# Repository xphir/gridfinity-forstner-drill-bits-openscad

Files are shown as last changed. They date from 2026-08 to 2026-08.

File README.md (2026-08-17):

# gridfinity-forstner-drill-bits-openscad

Parametric Gridfinity bin for Forstner drill bits. Bits lie flat in an open
tray, cradled by two notched rails, alternating head-to-tail ("top and
tail") so each bit's head sits next to a neighbour's narrow shaft — packing
the set far tighter than standing them upright would.

Built on [kennetek/gridfinity-rebuilt-openscad](https://github.com/kennetek/gridfinity-rebuilt-openscad)
for the base profile, stacking lip, walls, and magnet/screw holes. This repo
only adds the rail geometry that cradles the bits.

Inspired by [PabloFernandez](https://www.printables.com/@PabloFernandez)'s
[Gridfinity Bins for Forstner Drill Bits](https://www.printables.com/model/870351-gridfinity-bins-for-forstner-drill-bits)
on Printables.

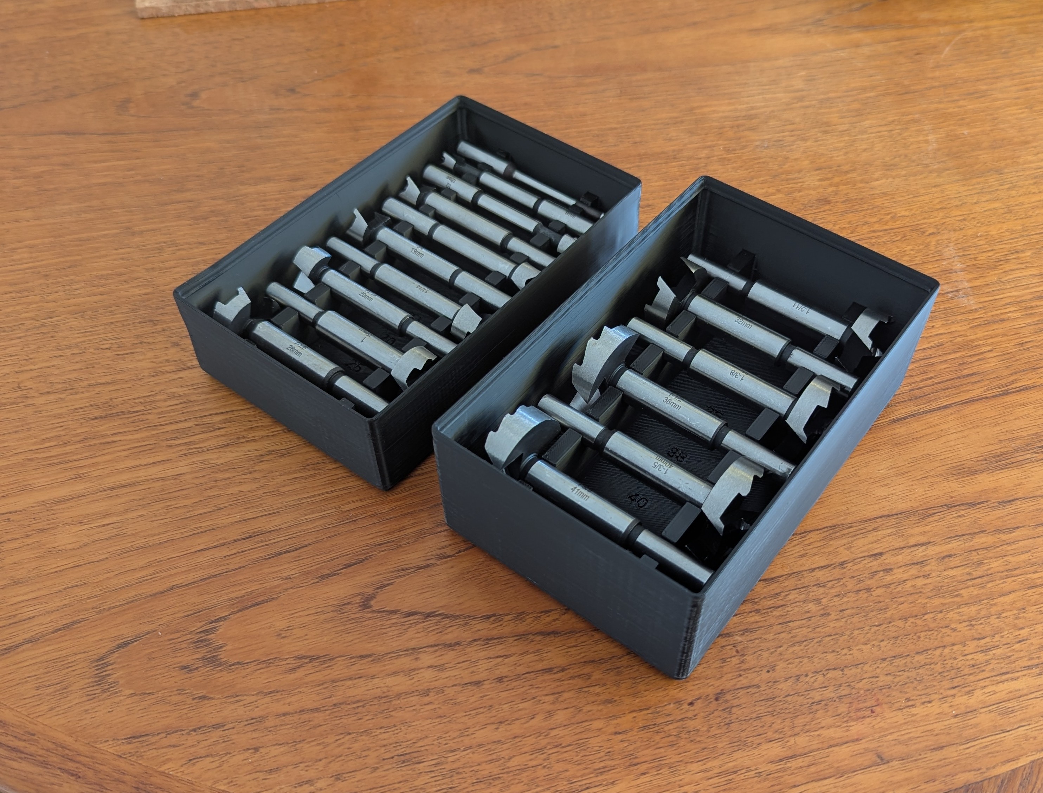
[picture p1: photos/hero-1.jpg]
Two printed trays, one sized for a small-bit set and one for a large-bit set


## Setup

The library is a git submodule, so clone with `--recurse-submodules`:

```bash
git clone --recurse-submodules https://github.com/xphir/gridfinity-forstner-drill-bits-openscad.git
```

If you already cloned without that flag:

```bash
git submodule update --init
```

Open `gridfinity_forstner_flat_lib.scad` in [OpenSCAD](https://openscad.org/).

## Usage

The bit list is up to 20 slots (`bit_01_*` through `bit_20_*`), each with its
own `enabled` checkbox — flip a slot on and fill in its dimensions to add a
bit, or leave it off to skip it. Out of the box, only 5 slots are enabled
with generic round sizes (10/15/20/25/30 mm) as a working example — replace
them with your own measurements, or load a known set via **Preset**. All
dimensions are in mm, measured from the head end downwards, five sections
per bit:

- `head_diameter` / `head_length` — the cutting head, the widest part
- `neck_diameter` / `neck_length` — short narrow transition right below the head
- `body_diameter` / `body_length` — the main shaft (most of the bit's length)
- `waist_diameter` / `waist_length` — narrow retention groove just above the shank
- `base_diameter` / `base_length` — the shank that goes in the chuck

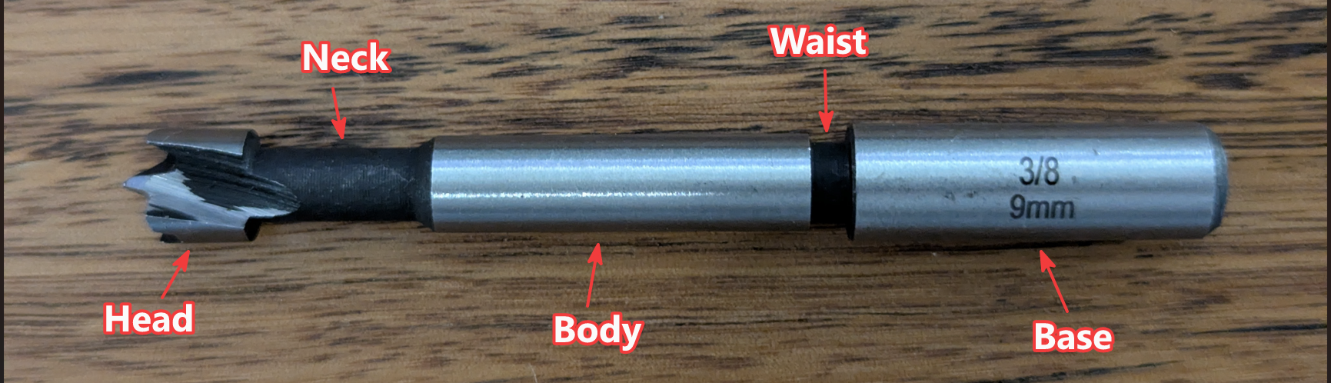
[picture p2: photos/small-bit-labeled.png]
Small Forstner bit segments labelled: head, neck, body, waist, base

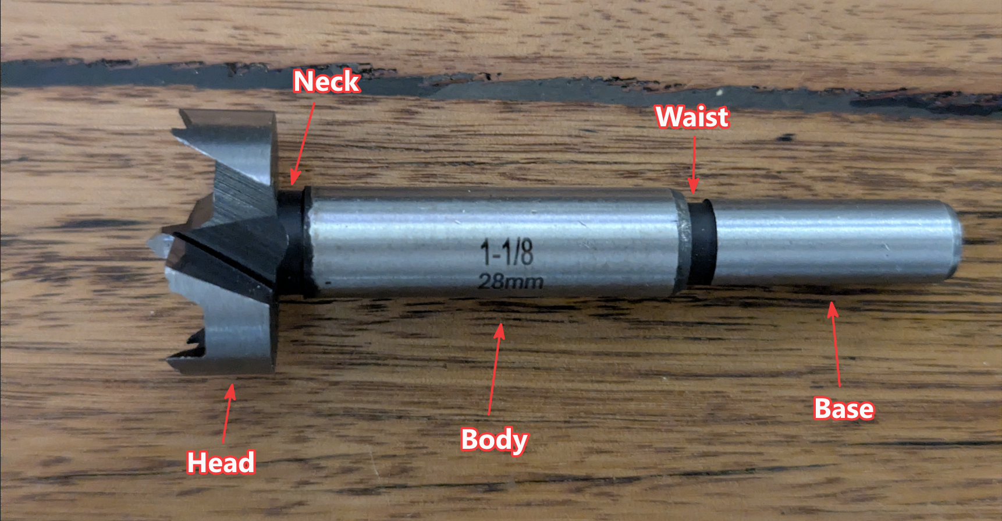
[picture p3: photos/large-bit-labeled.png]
Large Forstner bit segments labelled: head, body, waist, base


Only `head_diameter` needs a value on every enabled bit. Everything else
defaults to `0`, which means "use the matching `default_head_length` /
`default_body_diameter` / etc. value" in the **Bit defaults** section —
handy since most forstner sets share the same head length and shank across
many sizes. Give a bit a non-zero value in any of those fields to override
the default just for that one bit (e.g. if its shaft is a single constant
diameter, set that bit's `base_diameter` equal to its `body_diameter`).

Each bit also has a `mountN` field (`false` = body, `true` = neck), which
picks which of those two diameters actually grips that bit's rails. Most
bits should stay on `body`; switch a bit to `neck` if its body is short or
oddly proportioned next to its neighbours (a small bit whose neck is
proportionally long next to its shank, for example) — the model will warn
in the console if neither rail actually lands on the chosen section.

This scalar-per-field format (rather than a table or list) is deliberately
the most restrictive customizer-compatible shape there is, so it has the
best chance of showing up as editable fields both in the OpenSCAD Customizer
and in MakerWorld's parameter panel — neither reliably renders list-type
parameters.

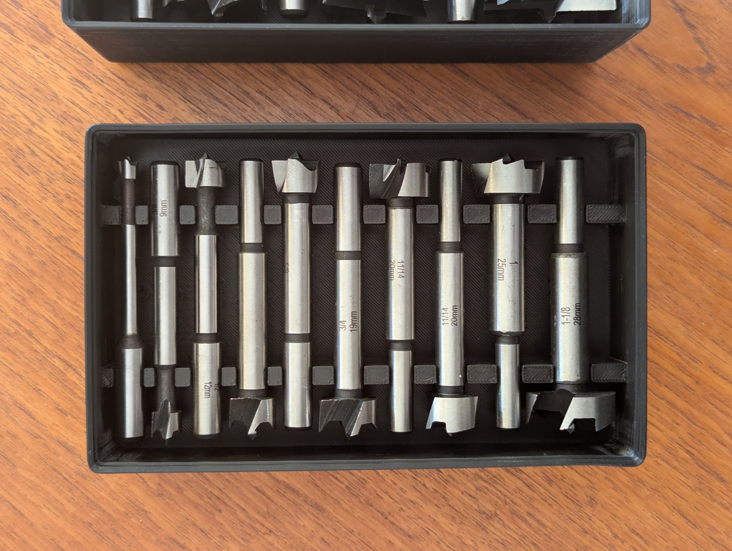
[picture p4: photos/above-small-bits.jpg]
Top-down view of a tray showing bits alternating head-to-tail


Everything else — bin footprint, height, rail spacing, magnet/screw holes,
labels — auto-sizes from the enabled bits, or can be overridden in the
Customizer. See the comments in `gridfinity_forstner_flat_lib.scad` itself
for the full parameter reference.

### Known bit sets

The **Preset** dropdown can load a known set's measurements into the bit
fields for you (currently just the VEVOR 16-piece set). A preset only fills
in *sizes* — one preset row per slot — it never touches the `enabled`
checkboxes, so you can still turn individual slots on/off same as with a
hand-entered list. Pick `None` to go back to editing the fields yourself.

### Splitting a large set across multiple prints

A full 16+ bit set makes for a long tray and a long print. Since rail
spacing is shared across every enabled bit, splitting the set into two
prints — rather than just picking a smaller `grid_x`/`grid_y` — keeps each
print's rail spacing tuned to a narrower size range instead of being
stretched to fit both your smallest and largest bits at once. It also
just plain fits more printer beds — a single tray sized for a full 16+
bit set can easily be longer than many printers' build volume. With the
VEVOR set, for example: enable bits 1–10 for one print, then 11–16 for a
second, by flipping the rest off in **Enabled bits** (works the same way
whether you're using the preset or a hand-entered list).

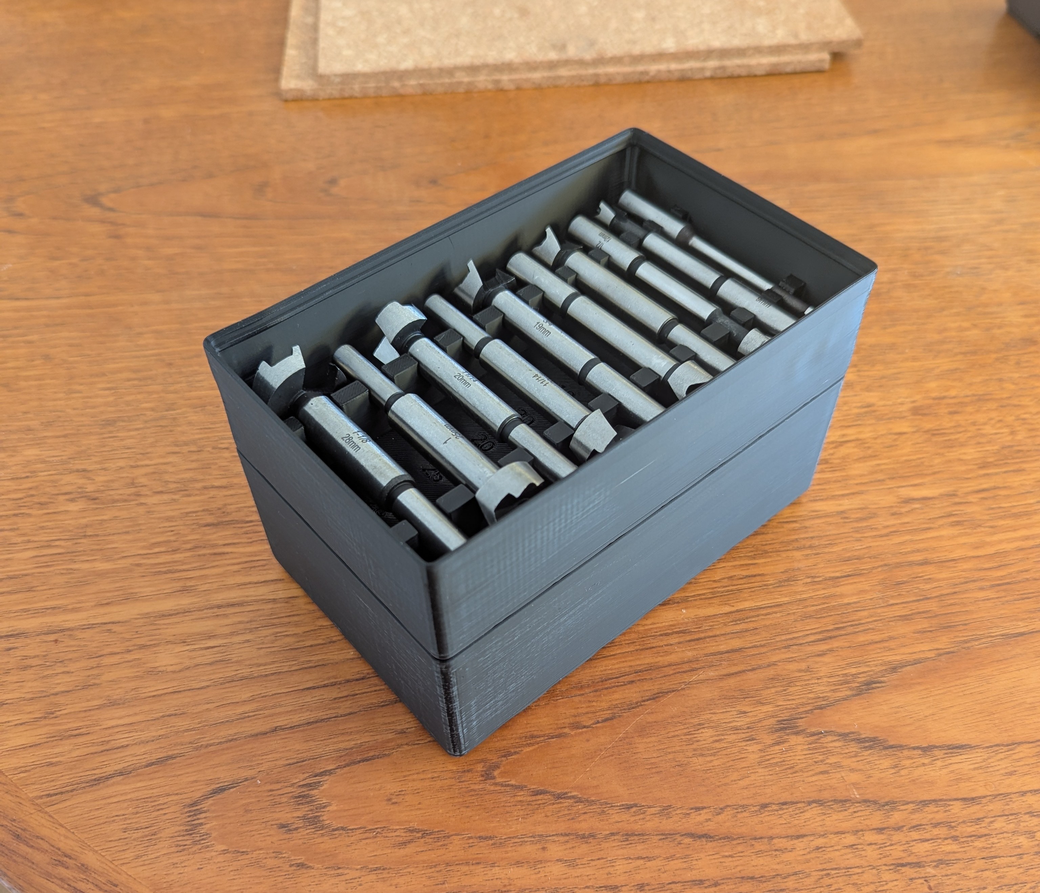
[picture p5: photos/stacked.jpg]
Two trays stacked, one for the small-bit split and one for the large-bit split


### Half-grid footprint

Set `allow_half_units` (in **Bin**) to size the tray in 21 mm half-units
instead of full 42 mm Gridfinity units, for a tighter footprint when a
full unit per row would waste space. It still snaps onto a standard
Gridfinity baseplate.

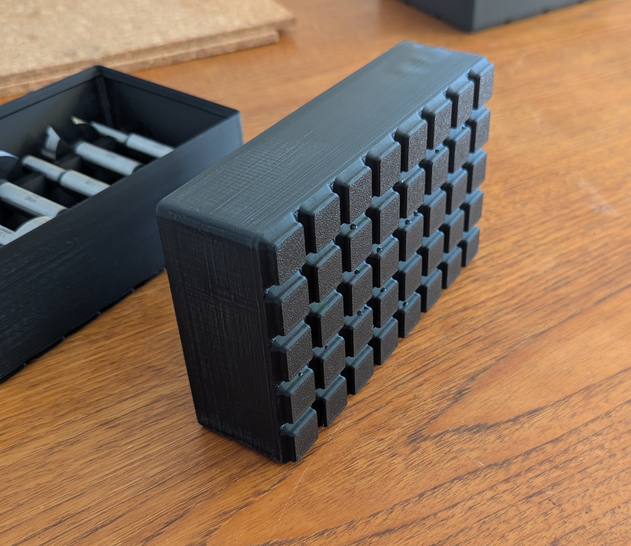
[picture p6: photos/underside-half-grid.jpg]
Underside of a tray printed with the half-grid footprint


### Testing grip/fit before committing to a full print

Set `test_bit` (in **Testing**) to a slot number to render a small, fast
coupon instead of the whole bin — just enough rail to test-fit that one
bit and feel whether the retention pinch actually grips. Much quicker than
re-printing the full tray while dialing in `slot_clearance` and
`grip_pinch` for your printer/filament. Worth doing even with the default
`slot_clearance` — the right value depends on your printer and filament,
and is cheap to check with the coupon before committing to a full tray.

Set `test_all_bits` instead to render one connected, height-reduced rail
strip covering every enabled bit at its real spacing — a single quick
print that checks the whole set's fit, including bit-to-bit spacing, not
just each bit in isolation. It overrides `test_bit` while on.

## Gallery

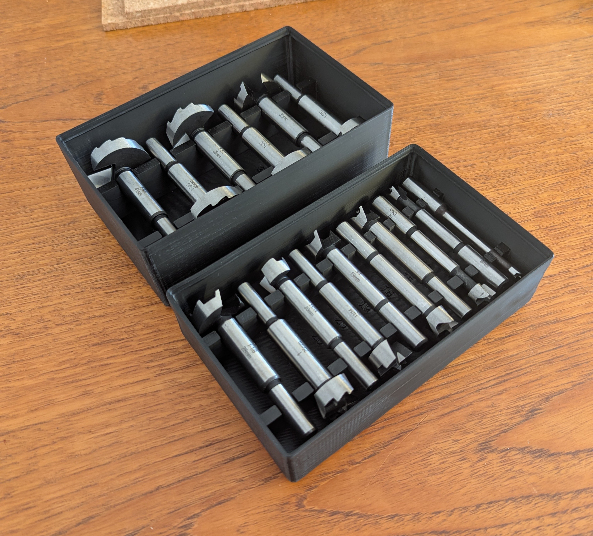
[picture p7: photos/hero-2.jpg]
Angled close-up of both trays

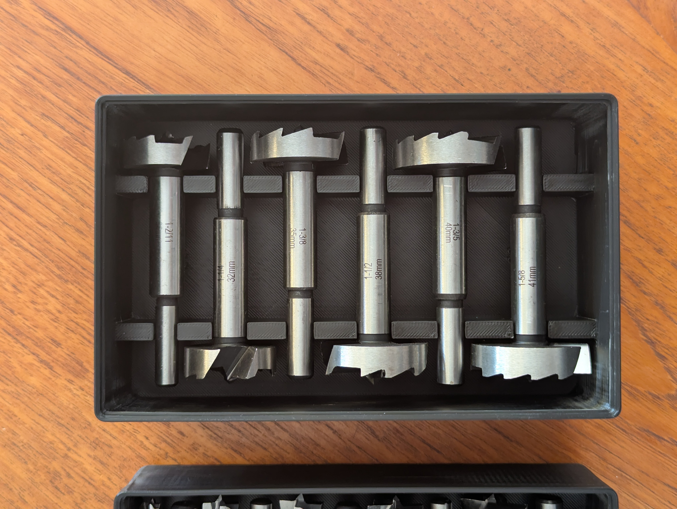
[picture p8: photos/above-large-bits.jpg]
Top-down view of the large-bit tray

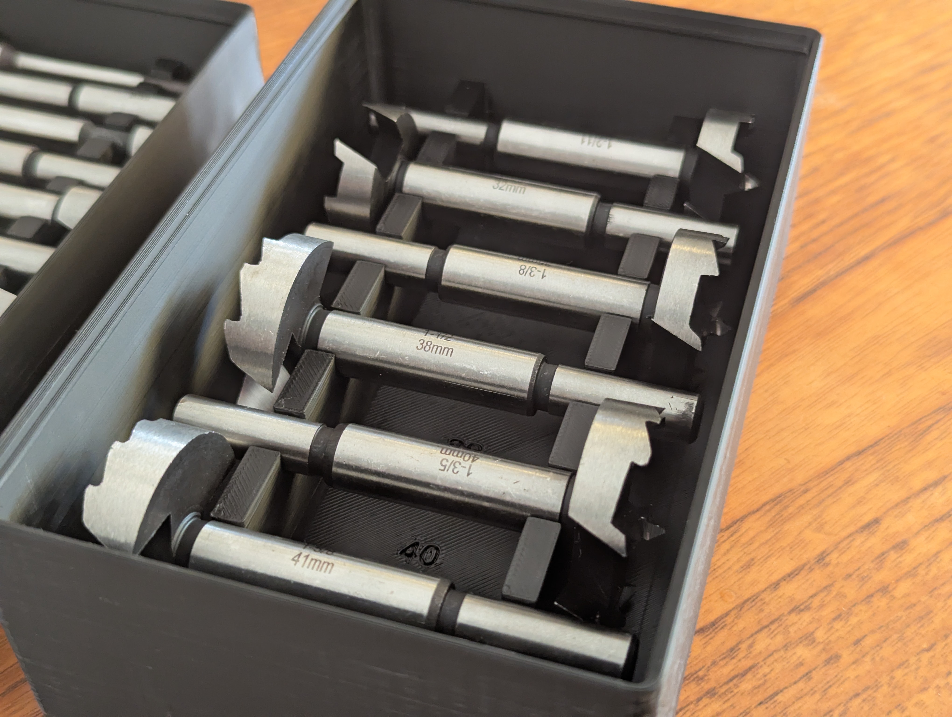
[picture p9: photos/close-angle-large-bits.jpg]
Closer angled view of the large-bit tray


## Status

Verified to compile to a clean manifold solid. First real test print
confirmed the flat-lay/top-and-tail layout works and the retention pinch
gives a real click. At the default `slot_clearance` (0.05 mm) bits click
in and hold well — even fully upside down, nothing falls out — but it can
be a little tight to pull bits back out; try 0.1 mm if you'd rather have
easier removal at the cost of a slightly less snug hold. Use `test_bit` to
check either value on your own printer before committing to a full tray.

Printed in [Siddament Black PLA+](https://siddament.com.au/products/black-pla-1)
on a 0.4 mm nozzle, 0.2 mm layers, Arachne walls, 3 wall loops, 15% gyroid
infill. Some stringing showed up in corners, most likely from damp
filament rather than the model or slicer settings. A ready-to-slice
[`profiles/vevor-16-bit-set.3mf`](profiles/vevor-16-bit-set.3mf) is
included for the VEVOR 16-piece set as a starting point.

The VEVOR preset's dimensions come from a real set; anything you enter by
hand should still be measured against your own bits before printing.

## License

MIT — see [LICENSE](LICENSE). The bundled `gridfinity-rebuilt-openscad`
submodule is separately licensed (also MIT) by its own authors.

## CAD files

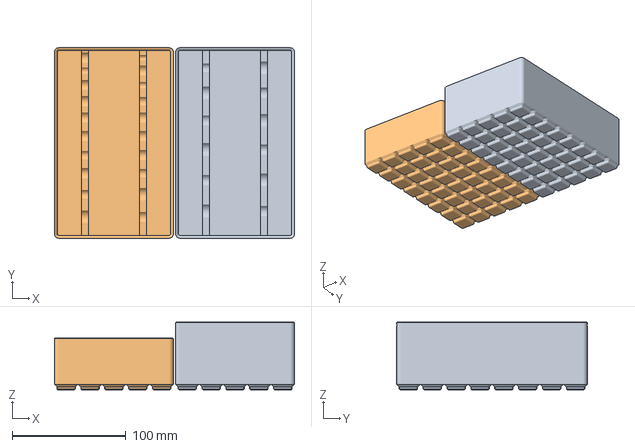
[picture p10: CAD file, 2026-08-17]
profiles/vevor-16-bit-set.3mf
211.0 x 167.5 x 59.5 mm
ParametricModelMaker(4).stl
ParametricModelMaker(3).stl

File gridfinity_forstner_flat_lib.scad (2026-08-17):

// =============================================================================
//  GRIDFINITY FORSTNER BIT HOLDER  -  flat lay, top-and-tail
//  Built on kennetek's gridfinity-rebuilt-openscad library.
// -----------------------------------------------------------------------------
//  SETUP
//    git clone https://github.com/kennetek/gridfinity-rebuilt-openscad.git
//  and put the resulting folder next to this file:
//
//    my-project/
//      gridfinity_forstner_flat_lib.scad     <- this file
//      gridfinity-rebuilt-openscad/          <- the cloned library
//
//  The library owns the base profile, stacking lip, walls and magnet/screw
//  holes. This file only adds the two notched rails that cradle the bits.
//
//  F5 = preview, F6 = render, then File > Export > Export as STL.
// =============================================================================

include <gridfinity-rebuilt-openscad/src/core/standard.scad>
use <gridfinity-rebuilt-openscad/src/core/bin.scad>
use <gridfinity-rebuilt-openscad/src/core/gridfinity-rebuilt-holes.scad>
use <gridfinity-rebuilt-openscad/src/core/gridfinity-rebuilt-utility.scad>


// =============================================================================
//  BIT LIST -- up to 20 slots (Bit defaults, then Enabled bits, then Bit
//  list, near the bottom of the Customizer). Turn a slot off in "Enabled
//  bits" to skip it entirely; disabled slots don't affect sizing/layout at
//  all. All dimensions in mm,
//  measured from the head end downwards, five sections per bit (see
//  photos/ for a labelled reference):
//
//    head  -- the cutting head, the widest part
//    neck  -- short narrow transition right below the head
//    body  -- the main shaft (most of the bit's length)
//    waist -- narrow retention groove just above the shank
//    base  -- the shank that goes in the chuck
//
//  head_diameter is always read from the bit's own field -- it's the one number
//  that actually distinguishes one bit from another. Every other field
//  (head_length, neck_diameter, neck_length, body_diameter, body_length, waist_diameter, waist_length,
//  base_diameter, base_length) defaults to 0, meaning "use the matching default_*
//  value in Bit defaults" -- most forstner sets share the same head length
//  and shank across many sizes, so this saves re-typing the same numbers
//  20 times. Give a bit its own non-zero value in any of those fields to
//  override the default just for that bit.
//
//  mountN picks whether that bit's rails grip its neck or its body
//  (default body). Rather than exactly track where the neck/body/waist
//  boundaries physically fall -- fragile once bit proportions vary this
//  much between sizes -- the seat at BOTH rails for a bit is simply sized
//  to whichever one is chosen, treated as if it ran the bit's whole shaft
//  length. If a bit's body is too short/oddly proportioned relative to its
//  neighbours (like a small bit's neck being proportionally huge next to
//  its shank), switch that bit's mount to neck instead.
//
//  This is scalars-per-bit (instead of one table, or even parallel lists)
//  because it's the most restrictive customizer-compatible format there
//  is -- plain numbers and booleans, nothing structured -- so it has the
//  best chance of showing up as editable fields in both the OpenSCAD
//  Customizer and MakerWorld's parameter panel, neither of which reliably
//  supports list-type parameters.
// =============================================================================

/* [Preset] */
// Loads a known bit set's sizes into the fields below (slot 1 = the preset's first bit, etc.), overriding whatever is typed there; Enabled bits below still controls what's included. None = edit the fields yourself.
preset = "none"; // [none:None, vevor16:VEVOR 16 Pcs Forstner Bit Set]


/* [Layout] */

// Reverse every second bit (top and tail). Off = all heads the same end.
alternate = true;
// Sort the bit list largest-head-first before laying out. Off = keep the order you typed them in (useful for testing a specific arrangement).
sort_bits = true;
// Air gap between neighbouring bits, mm (all measurements below are mm too).
bit_gap = 2; // .5
// Gap between the ends of the bits and the inside of the bin wall
end_gap = 2; // .5
// Air under the heads, so you can get a finger under a bit to lift it
head_floor_gap = 2; // .5


/* [Rails] */

// Distance between the two rails, mm. 0 = auto (as far apart as the bits allow).
rail_gap = 0; // .5
// Width of each rail (and the seat cut into it) along the bit's length.
rail_width = 6; // .5
// Keep the rail at least this far clear of the back of the head
rail_margin = 1.5; // .5
// Extra radius added to every seat so bits aren't a dead-tight press fit.
slot_clearance = 0.05; // .01
// How far the seat continues straight up past the shaft centreline
grip = 1.5; // .5
// Funnel widening at the mouth of each seat
slot_flare = 1.2; // .1
// Minimum material left between two neighbouring seats
rail_wall = 1.6; // .1
// How much narrower than the bit's radius the retention pinch is, mm, so bits click into place instead of resting loosely; 0 = no pinch (plain funnel). Dial in with a test swatch (see [Testing]).
grip_pinch = 0.2; // .05
// How far above the seat's straight-walled cradle (grip) the pinch sits.
grip_pinch_height = 1; // .5


/* [Bin] */

// Footprint in gridfinity units (grid_x = length, grid_y = depth); 0 = auto-size to the bits.
grid_x = 0;
grid_y = 0;
// Use a 21 mm base pitch instead of the standard 42 mm one, for a more compact (half-unit) footprint; magnet/screw holes follow the same 21 mm pitch, so won't align with a standard 42 mm baseplate's holes.
allow_half_units = false;
// Height in gridfinity units (7 mm each). 0 = auto.
height_units = 0;
// Extra floor, mm, on top of the library's 7 mm base (usually leave at 0); if include_lip is off this MUST be > 0, since without a lip the walls are built from the floor's infill.
extra_floor = 0; // .1
// Air above the tallest bit (mm). Only used when height_units = 0 (auto).
top_clearance = 2; // .5

// Stacking lip around the top rim, so another bin can stack on this one; if off, see the extra_floor note above.
include_lip = true;


/* [Base holes] */
// Hole for a 6mm magnet in each base cell.
magnet_holes = false;
// Hole for an M3 screw in each base cell.
screw_holes = false;
// Ribs that grip a pressed-in magnet without glue (only if magnet_holes is on).
crush_ribs = true;
// Chamfer the top edge of the hole(s) (only if magnet_holes and/or screw_holes is on).
chamfer_holes = true;
// Print the hole(s) without support material (only if magnet_holes and/or screw_holes is on).
supportless = true;
// Put holes in the outer corner cells only, instead of every cell (only if magnet_holes and/or screw_holes is on).
only_corners = false;


/* [Labels] */
// Engrave each bit's label (from the bit list) into the floor under it.
labels = true;
// Text height (mm). Only has an effect if labels is on.
label_size = 5; // .5
// How deep the text is cut into the floor (mm). Only has an effect if labels is on.
label_depth = 0.6; // .05


/* [Bit defaults] */
// All values in mm. Fallback used by any bit below that leaves its own matching field at 0 (does not apply to head_diameter, which always comes from the bit's own field).
default_head_length = 15; // .5
default_neck_diameter = 8; // .5
default_neck_length = 0; // .5
default_body_diameter = 8; // .5
default_body_length = 40; // .5
default_waist_diameter = 8; // .5
default_waist_length = 0; // .5
default_base_diameter = 8; // .5
default_base_length = 25; // .5


/* [Enabled bits] */
// Which of the 20 slots below are active (independent of Preset above; grouped here so you can flip them all at a glance).
bit_01_enabled = true;
bit_02_enabled = true;
bit_03_enabled = true;
bit_04_enabled = true;
bit_05_enabled = true;
bit_06_enabled = false;
bit_07_enabled = false;
bit_08_enabled = false;
bit_09_enabled = false;
bit_10_enabled = false;
bit_11_enabled = false;
bit_12_enabled = false;
bit_13_enabled = false;
bit_14_enabled = false;
bit_15_enabled = false;
bit_16_enabled = false;
bit_17_enabled = false;
bit_18_enabled = false;
bit_19_enabled = false;
bit_20_enabled = false;


/* [Bit list] */

// Bit 01: dimensions in mm; 0 = use Bit defaults, except head_diameter; ignored for slots a Preset already covers.
bit_01_head_diameter = 10;
bit_01_head_length = 0;
bit_01_neck_diameter = 0;
bit_01_neck_length = 0;
bit_01_body_diameter = 0;
bit_01_body_length = 0;
bit_01_waist_diameter = 0;
bit_01_waist_length = 0;
bit_01_base_diameter = 0;
bit_01_base_length = 0;
bit_01_mount_neck = false;

// Bit 02
bit_02_head_diameter = 15;
bit_02_head_length = 0;
bit_02_neck_diameter = 0;
bit_02_neck_length = 0;
bit_02_body_diameter = 0;
bit_02_body_length = 0;
bit_02_waist_diameter = 0;
bit_02_waist_length = 0;
bit_02_base_diameter = 0;
bit_02_base_length = 0;
bit_02_mount_neck = false;
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

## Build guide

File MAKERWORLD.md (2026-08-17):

# MakerWorld listing description

Copy/paste source for the MakerWorld listing. Not linked from the README —
this is just where the listing text lives so it's versioned with the model.

---

## Title

Gridfinity Forstner Bit Holder (Parametric)

(43 chars — MakerWorld's model name field caps out at 50.)

## Category

Organizers

## Tags

- parametric
- customisable
- gridfinity
- forstner bit
- bit
- tool

## Description

<!-- IMAGE: photos/hero-1.jpg — two trays side by side, small-bit set + large-bit set -->

A parametric Gridfinity tray for Forstner bits that actually fits *your*
set — enter your bits' measurements (or pick a known preset) and it
generates a custom holder sized exactly for them.

Forstner bits don't stack neatly like twist drills: the head is much wider
than the shank, so upright holders waste a ton of space. This tray lays
bits flat instead, alternating head-to-tail ("top and tail") so each bit's
wide head sits next to a neighbour's narrow shaft. Two notched rails cradle
each bit at its shaft, with a small retention pinch moulded into the seat
so bits click in and stay put instead of rattling around.

<!-- IMAGE: photos/above-small-bits.jpg — top-down shot showing the head-to-tail packing -->

**Works with MakerWorld's Customise button** — every field is a plain
number or checkbox, no fiddly list editing required.

### Features

- **Fits any Forstner set** — describe up to 20 bits (diameter + length for
  head/neck/body/waist/shank) and the tray sizes itself automatically.
- **Built-in preset** — the VEVOR 16-piece Forstner set is included as a
  one-click preset; just toggle which sizes you actually own.
- **Real retention grip** — a moulded pinch in each rail seat, not just a
  funnel, so bits hold with a light click instead of sliding loose.
- **Handles odd bit shapes** — some bits have a thin "neck" between head
  and shaft that's too short to grip normally; a per-bit switch lets you
  choose whether the rail grips the neck or the main body, with a warning
  if a bit's geometry won't work with either.
- **Test coupon mode** — render a small single-bit test piece instead of
  the full tray so you can dial in clearance/grip for your printer and
  filament before committing to a long print.
- **Split large sets across multiple prints** — rail spacing is tuned to
  the enabled bits, so a 16+ bit set prints better as two trays than one
  stretched-out tray.
- **Gridfinity-native base** — snaps onto any standard Gridfinity
  baseplate, including half-size (21 mm) footprints for tighter packing.
- **Auto-sized labels** engraved under each bit slot.

<!-- IMAGE: photos/stacked.jpg — two trays stacked, illustrating a split large set -->

### How to use it

1. Hit **Customise** on the print page (or open it in OpenSCAD's
   Customizer for the full experience).
2. Either pick a **Preset** (e.g. VEVOR 16 Pcs) and just toggle
   **Enabled bits**, or leave Preset on `None` and fill in your own bits'
   measurements under **Bit list** (it ships with a 5-bit generic example
   to start from).
3. Only `head_diameter` is required per bit — everything else falls back to
   sensible defaults you set once under **Bit defaults**.
4. **Strongly recommended:** before printing the full tray, set `test_bit`
   under **Testing** to a slot number (or `test_all_bits` for a single
   height-reduced strip covering every enabled bit at its real spacing)
   and print that small coupon first — it takes minutes, not hours, and
   lets you dial in `slot_clearance` / `grip_pinch` for your printer and
   filament so the bits actually fit.
5. Once the coupon(s) fit the way you want, set `test_bit = 0` and
   `test_all_bits = false`, then print the full tray.

Full field-by-field reference and split-print guidance are on the
[GitHub repo](https://github.com/xphir/gridfinity-forstner-drill-bits-openscad).

### Print settings

<!-- IMAGE: photos/underside-half-grid.jpg — underside showing the half-grid Gridfinity base feet -->

My prints used the `allow_half_units` half-grid (21 mm) base — it dropped
the footprint from 3x4 grids to 2.5x4 for the same bits, a noticeably more
compact tray. Still snaps onto a standard Gridfinity baseplate.

Printed and tested with: 0.4 mm nozzle, 0.2 mm layers, Arachne walls,
3 wall loops, 15% gyroid infill, no supports needed. [Siddament Black
PLA+](https://siddament.com.au/products/black-pla-1) worked well; any
PLA/PLA+ should be fine.

At the default `slot_clearance` (0.05 mm) bits click in and hold firmly —
even fully upside down, nothing falls out — but they can be a little tight
to pull back out. Try 0.1 mm if you'd rather have easier removal at the
cost of a slightly less snug hold. Either way, check it with the
`test_bit` coupon on your own printer before committing to a full tray —
grip depends on your printer and filament.

### Credit

Base profile, stacking lip, and magnet/screw holes come from
[kennetek/gridfinity-rebuilt-openscad](https://github.com/kennetek/gridfinity-rebuilt-openscad)
(MIT licensed). This model only adds the bit rail geometry.

Inspired by PabloFernandez's [Gridfinity Bins for Forstner Drill Bits](https://www.printables.com/model/870351-gridfinity-bins-for-forstner-drill-bits)
on Printables.

### License

The source (GitHub repo) is MIT. MakerWorld doesn't offer MIT as a listing
license — it only offers Creative Commons-style toggles — so the closest
equivalent there is CC-BY.

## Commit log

2026-08-15 feat: gridfinity forstner bit holder
    Parametric Gridfinity bin for Forstner drill bits, laid flat and cradled
    by two notched rails, alternating head-to-tail so each head sits beside
    a neighbour's narrow shaft. Built on kennetek's gridfinity-rebuilt-openscad
    (pinned submodule) for the base profile, walls, stacking lip, and
    magnet/screw holes.
    Up to 20 bits, each its own enable checkbox, plain scalar fields only so
    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
    [gridfinity_forstner_flat_lib.scad]
2026-08-15 refactor: move label to under bits
    [gridfinity_forstner_flat_lib.scad]
2026-08-16 feat: model bits as five segments with a neck/body mount selector
    Splits the old head/neck/base model into head/neck/body/waist/base,
    matching how forstner bits actually look (see photos/): a short neck
    transition below the head, the main body shaft, and a narrow waist
    groove above the shank. neck/waist default to zero-length so simple
    bits still only need head+body+base.
    Adds a per-bit mountN field (body default, or neck) that picks which
    diameter grips that bit's rails, since a shared rail spacing can land
    on a thin, unintended transition for bits with unusual proportions
    (e.g. a short bit whose neck is proportionally long next to its
    shank) -- confirmed with a 9mm-bit-proportioned test c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
    [gridfinity_forstner_flat_lib.scad]
2026-08-16 feat: add a retention pinch to the seat for actual grip
    Bits previously just rested in clearance-fit seats with no grip --
    fine for the width but nothing stopping them sliding around loosely.
    Reshapes the seat's funnel into three stages instead of one: a
    straight-walled cradle at the bit's own diameter, a pinch slightly
    narrower than the bit partway up (grip_pinch, default 0.2mm), then a
    funnel back out to ease insertion. The bit has to press past the
    pinch to seat, then it's held captive below it.
    grip_pinch = 0 collapses back to the original plain funnel. Verified
    manifold across a range of pinch values.
    [gridfinity_forstner_flat_lib.scad]
2026-08-16 feat: add a test swatch for quick grip/fit iteration
    Printing the whole bin just to check whether grip_pinch or
    slot_clearance feels right is slow and wasteful. test_bit renders a
    small standalone coupon instead -- a short strip of both rails with
    one bit's two seats cut in, matching the same geometry the full bin
    would produce. Renders in milliseconds since it's a handful of cubes
    and two seat cuts, not a whole bin.
    [gridfinity_forstner_flat_lib.scad]
2026-08-16 fix: stop the mount warning false-positiving on the base zone
    mount_ok() required both rail positions to fall strictly within the
    chosen mount segment's own span, but landing past it in the base zone
    is completely fine -- dia_at() already sizes that correctly regardless
    of mount. Confirmed with a real 16-bit set (no neck/waist modelled at
    all): every single bit false-positived, since with those segments at
    zero length the mount span ends exactly where the base begins.
    Now only flags landing in the genuinely wrong spot: the other,
    non-chosen one of neck/body, or the waist. Verified the false positive
    is gone on that 16-bit set, and that a real mismatch (forcing a rail
    into a bit's neck zone)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
    [gridfinity_forstner_flat_lib.scad]
2026-08-16 feat: fill in real 16-bit forstner set as the default bit list
    Replaces the placeholder demo data with an actual measured set,
    enabled by default. head_len is uniform at 15mm across the whole set,
    matching default_head_len, so it's left at 0 (use default) throughout
    rather than repeated on every bit. No neck/waist measured for this
    set, so those stay off (0-length) and mount defaults to body
    everywhere -- matches the old 3-segment data this set originally came
    from.
    Verified manifold with no warnings.
    [gridfinity_forstner_flat_lib.scad]
2026-08-16 fix: test_bit was indexing sorted order, not the bit01/02/... slots
    test_bit=1 picked the largest bit (first in the sorted, largest-first
    layout order) instead of bit01 as labelled in the Customizer -- e.g.
    with the current set, test_bit=1 rendered the 41mm bit's seat, not
    the 6mm bit in slot 1. order[] maps sorted position to original slot
    position, so look up which sorted position corresponds to the slot
    number the user actually asked for. Verified test_bit=1/2/8/16 now
    resolve to bits 6/9/20/41, matching the entry order exactly.
    [gridfinity_forstner_flat_lib.scad]
2026-08-17 fix: pinch was sitting above the rail's actual top surface
    rail_top (the solid rail block's real top face) was computed as
    axis_z + grip + 0.8, but the retention pinch sits at axis_z + grip +
    grip_pinch_height -- with the defaults (grip=1.5, grip_pinch_height=1)
    that's axis_z+2.5 against a rail_top of only axis_z+2.3, so the pinch
    landed 0.2mm past the end of the solid material. No plastic left there
    to actually squeeze the bit, so it did nothing regardless of
    grip_pinch strength -- confirmed by a real test print still feeling
    loose after the pinch was added.
    rail_top now accounts for grip_pinch_height so the pinch always has
    margin below the block's real top edge.
    Also tightens the defaul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
    [gridfinity_forstner_flat_lib.scad]
2026-08-17 feat: slim down the test swatch (no overhang, half height)
    Two changes to the swatch, purely for faster/cheaper test prints:
    - The connecting base no longer overhangs past the rail legs -- an
    upside-down Pi/U shape instead of a wide pad, and just a thin 2mm
    connector instead of the full gridfinity floor thickness.
    - Leg height halved. Everything below axis_z is plain material with
    no cutout in it, so shortening from the bottom (not the top) leaves
    the seat geometry completely untouched -- clamped so it can never
    shorten enough to reach into the cutout regardless of bit sizes.
    Verified identical facet count on the cutout itself before and after.
    [gridfinity_forstner_flat_lib.scad]
2026-08-17 feat: measure neck/waist for the three small bits, mount them on neck
    Bits 01-03 (6/9/12mm) get real head/neck/body/waist/base breakdowns
    instead of the placeholder body-only data, all mounted on neck --
    these are the short bits where the neck is proportionally large next
    to the shank, the exact case the neck/body mount split exists for.
    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
    [gridfinity_forstner_flat_lib.scad]
2026-08-17 feat: add a bit-set preset dropdown, with the VEVOR 16pc set built in
    Adds a preset dropdown (Custom, or a named known set) that, when set
    to anything but Custom, overrides the individual bitNN_* fields
    entirely -- including their enabled checkboxes -- with a baked-in
    table instead. Custom (the default) is unaffected: it still reads the
    fields exactly as before.
    The table lives as one internal function (preset_bits()) returning
    plain rows, not a customizer-exposed list, so it doesn't compromise
    the scalars-only format the rest of the bit list relies on for
    Customizer/MakerWorld compatibility. Ships with "VEVOR 16 Pcs Forstner
    Bit Set", transcribed from (and verified identical, byte-for-byte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
    [gridfinity_forstner_flat_lib.scad]
2026-08-17 fix: preset should only supply sizes, not bypass enabled/disabled
    A preset used to replace the individual bit slots wholesale, ignoring
    their enabled checkboxes entirely -- selecting a 16-bit preset always
    gave you all 16, with no way to print a subset without switching back
    to Custom and retyping everything.
    Now it's a per-slot overlay: slot i's SIZES come from the preset's row
    i when a preset is active, but "Enabled bits" still decides which
    slots are actually included -- e.g. enabling only bits 1-10 with the
    VEVOR preset active now correctly produces a 10-bit bin, letting a set
    be split across multiple prints without leaving preset mode.
    Verified: default (custom) and preset with all sl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
    [gridfinity_forstner_flat_lib.scad]
2026-08-17 docs: bring README up to date with the 5-segment model and presets
    Was still describing the old head/neck/base model and "nothing
    printed yet". Updates the bit-field reference to head/neck/body/waist/
    base plus mountN, documents the preset dropdown, and adds two
    practical sections: splitting a large set across multiple prints
    (rail spacing is shared across every enabled bit, so a narrower size
    range per print fits better than just shrinking grid_x/grid_y), and
    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
2026-08-17 feat: add VEVOR 16-piece bit set slicer profile
    [vevor-16-bit-set.3mf]
2026-08-17 docs: add real print notes, split-print bed-size note, profile link
2026-08-17 docs: add image placeholders and real print/license notes to MakerWorld listing
2026-08-17 docs: fix relative link, simplify license note, emphasize test print, fix Customise wording
2026-08-17 docs: note that the print used the half-grid base for a tighter footprint
2026-08-17 docs: clarify units on Customizer labels without repeating mm on every field
    [gridfinity_forstner_flat_lib.scad]
2026-08-17 refactor: rename bitNN_ fields to bit_NN_ so Customizer/MakerWorld labels read as "Bit 01"
    Also condense multi-line Customizer comments to a single line each -- only the last line of a multi-line comment block is shown as the field's tooltip, so anything split across lines was invisible or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
    [gridfinity_forstner_flat_lib.scad]
2026-08-17 refactor: spell out dia/len as diameter/length, reorder Customizer groups, drop -- from tooltips
    Field names like head_dia/head_len become head_diameter/head_length for
    clearer Customizer/MakerWorld labels. Groups now appear in a more natural
    order: Preset, Layout, Rails, Bin, Base holes, Labels, Bit defaults,
    Enabled bits, Bit list, Testing (previously the 20-bit table came first).
    Also fixed: only the LAST line of a multi-line comment is shown as a
    field's tooltip, so decorative "-- Bit 01 --" style headers were showing
    literal double-hyphens in the UI; condensed to single lines. Added notes
    where one option silently overrides or is overridden by another (e.g.
    Preset overwriting typed-in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
    [gridfinity_forstner_flat_lib.scad]
2026-08-17 feat: default Preset to None, ship a generic 5-bit example instead of the full VEVOR set
    The literal Bit list defaults previously duplicated the VEVOR 16-piece
    set's real measurements, which was redundant now that the same data is
    available via the Preset dropdown, and made "no preset selected" and
    "VEVOR set" look identical out of the box. The file now ships with 5
    generic round sizes (10/15/20/25/30 mm) enabled by default, a clearer
    starting example. Renamed the preset's off state from "custom" to "none"
    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
    [gridfinity_forstner_flat_lib.scad]
2026-08-17 feat: add test_all_bits to render every bit's test coupon on one plate
    Prints one labelled swatch per enabled bit, side by side, instead of
    testing grip/fit one bit at a time via test_bit. Refactored test_swatch()
    to take a sorted-layout index so both the single-bit and all-bits paths
    share the same geometry.
    [gridfinity_forstner_flat_lib.scad]
2026-08-17 fix: make test_all_bits one connected strip at real spacing, not separate swatches
    Reuses cy(i)/dL()/dR() the same way the full bin's rails() does, so the
    test piece mirrors the actual print's bit-to-bit spacing (not just each
    bit in isolation), while staying height-reduced like the single-bit
    test_swatch for a quick print.
    [gridfinity_forstner_flat_lib.scad]
2026-08-17 feat: add Customizer step/slider hints to tuning parameters
    Spinbox step-size comments (e.g. // .5) on the mm tuning knobs in Layout,
    Rails, Bin, Labels, and Bit defaults -- these only change the up/down
    arrow increment, never restrict what can be typed, so they're safe even
    though real-world values can fall outside any sensible default range.
    test_bit gets an actual slider (// [0:20]) since its range is a hard,
    code-enforced bound (there are only ever 20 bit slots) rather than a
    guess.
    Left the 20-bit table's own dimension fields (and the Bit defaults'
    fallback values) without range-restricting sliders on purpose: real
    Forstner bits vary too widely in size for any slider bound to be safe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
    [gridfinity_forstner_flat_lib.scad]
